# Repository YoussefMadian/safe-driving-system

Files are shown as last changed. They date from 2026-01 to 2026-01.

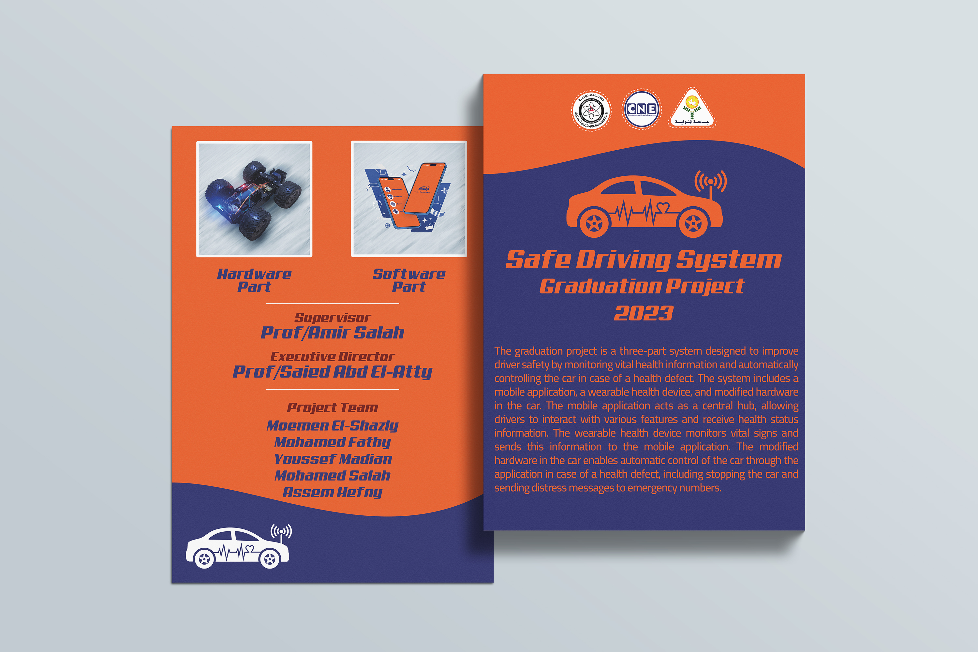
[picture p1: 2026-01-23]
Prints/Flyers/flyer.jpg

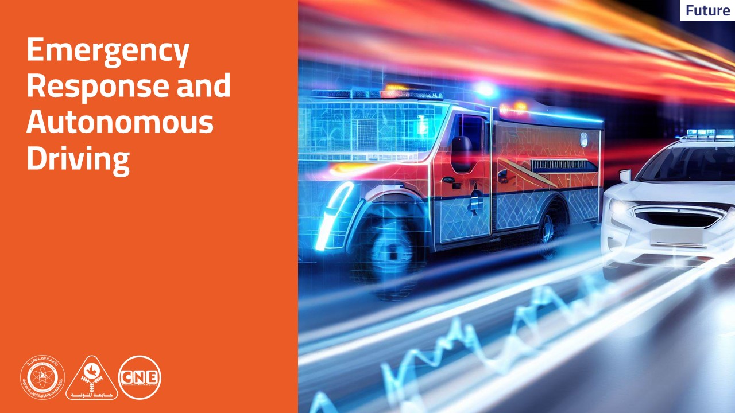
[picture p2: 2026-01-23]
Presentation/Photos/Slide62.JPG

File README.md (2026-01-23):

# safe-driving-system

## Overview
The **Safe Driving System** is an innovative graduation project designed to enhance road safety by monitoring drivers’ health conditions in real time. The system addresses a critical risk factor in driving accidents: sudden health issues that may impair a driver’s ability to operate a vehicle safely.

By combining **wearable health technology**, **wireless connectivity**, and a **mobile application**, the system provides continuous health monitoring, early detection of abnormal conditions, and timely alerts to assist drivers when needed.

---

## Problem Statement
Drivers may experience unexpected health complications such as abnormal heart rate or blood pressure fluctuations while driving. These conditions can significantly increase the risk of accidents if not detected early.

Traditional vehicles lack integrated systems capable of monitoring the driver's health status and responding intelligently to such situations.

---

## System Objectives
- Monitor vital health signs of the driver in real time  
- Detect abnormal physiological changes that may affect driving safety  
- Alert the driver immediately when critical conditions are detected  
- Enhance road safety and reduce accident risks caused by health issues  

---

## System Architecture
The Safe Driving System consists of **two main components**:

### 1. Mobile Application
- Acts as the central control and monitoring hub  
- Displays real-time health data in a user-friendly interface  
- Communicates with the wearable device via **Wi-Fi connection through the vehicle**  
- Sends alerts and notifications when abnormal health conditions are detected  

### 2. Wearable Health Device
- Worn by the driver during driving  
- Equipped with sensors to monitor vital signs such as:
  - Heart rate  
  - Blood pressure  
  - Other relevant physiological parameters  
- Continuously transmits health data to the mobile application  

---

## How the System Works
1. The wearable device continuously monitors the driver’s vital signs  
2. Health data is transmitted wirelessly to the mobile application  
3. The application analyzes incoming data in real time  
4. If abnormal values are detected:
   - The driver is alerted immediately  
   - The system suggests appropriate actions (rest, stop driving, seek medical help, etc.)  

---

## Technologies Used
- Wearable health sensors  
- Wi-Fi communication  
- Mobile application interface  
- Embedded system integration  
- Real-time data monitoring and analysis  

---

## Key Features
- Real-time health monitoring  
- Wireless communication between vehicle, wearable device, and mobile app  
- Early detection of health-related driving risks  
- User-friendly mobile interface  
- Improved driver safety and accident prevention  

---

## Project Scope
This project focuses on enhancing driver safety by integrating health monitoring systems into the driving environment. It demonstrates how **IoT**, **wireless networking**, and **mobile applications** can work together to solve real-world safety challenges.

---

## My Contribution
- System architecture design  
- Network and Wi-Fi integration between system components  
- Mobile application UI design  
- Branding and graphic design (logo, flyer, roll-up, presentation)  
- Documentation and final presentation  

---

## Future Enhancements
- Integration with emergency services  
- GPS-based location sharing during emergencies  
- Cloud-based data storage and analytics  
- AI-based health condition prediction  

---

## License
This project is developed for academic purposes as a graduation project.

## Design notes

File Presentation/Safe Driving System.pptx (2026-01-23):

## Safe Driving System

Graduation Project

2023

## Supervisor

Prof. Amir Salah

## Team Members

Youssef Madian

Asem Hefny

Mohamed Fathy

Mohamed Salah

Moemen El-Shazly

## Why Do We Need “Safe Driving System” ?

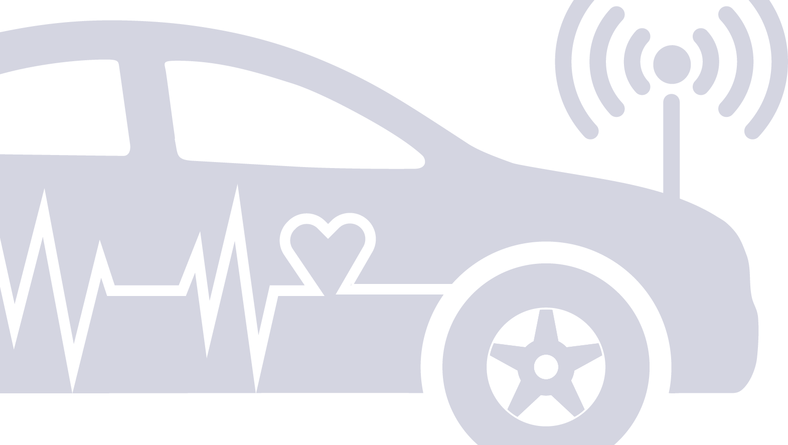
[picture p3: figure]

## Problem Statement

Every day, millions of people get behind the wheel, but what happens when a driver experiences a sudden health issue?

## Statistics On Deaths And Accidents

Globally, an estimated 1.6 million people die each year in road traffic crashes. Of these, up to 10%
(130,000) are believed to be the result of drivers experiencing a health problem while driving.
The leading health problems that commonly cause drivers to be involved in accidents are:
[Sudden cardiac arrest-Stroke-Diabetes-Seizures]

7.88 Billion

1.6 Million

130 Thousands

## The Need For A Solution !

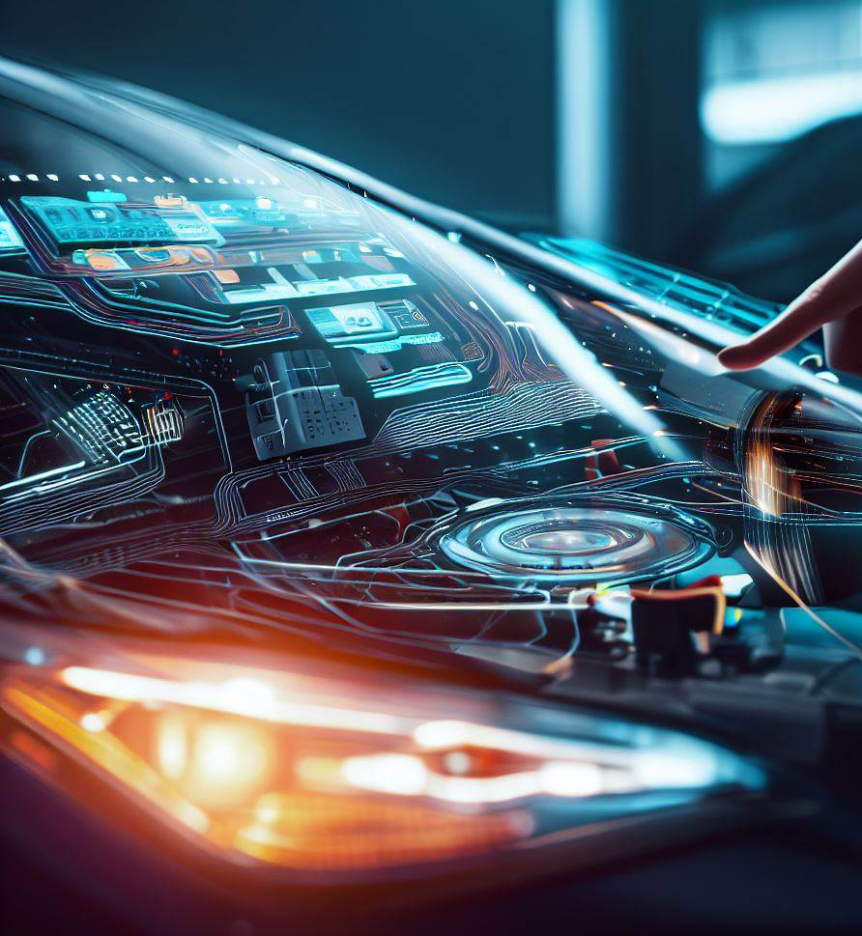
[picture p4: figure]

## Introduction About The Safe Driving System

This is where our solution “Safe Driving System” comes in. It's a three-part system consisting of a mobile
application and a wearable health device beside the hardware part in the simulator car.

## Introduction About The Safe Driving System

The mobile application serves as the central hub, providing a user-friendly interface for drivers to interact with various features and receive vital health status information.

## Introduction About The Safe Driving System

The wearable health device, on the other hand, monitors vital signs such as hearth rate and blood pressure and send this information to the mobile application.

## Introduction About The Safe Driving System

The modified hardware in the simulator car allows us to automatically control the car through the application after a health defect occurs, where the car is stopped and distress messages are sent to the specified emergency numbers.

## Project Overview

Servo Motor180

ESP8266

Arduino

DC Motor

L298d H-Bridge

I2C Logic Converter

Wearable Device

Application

## Outlines

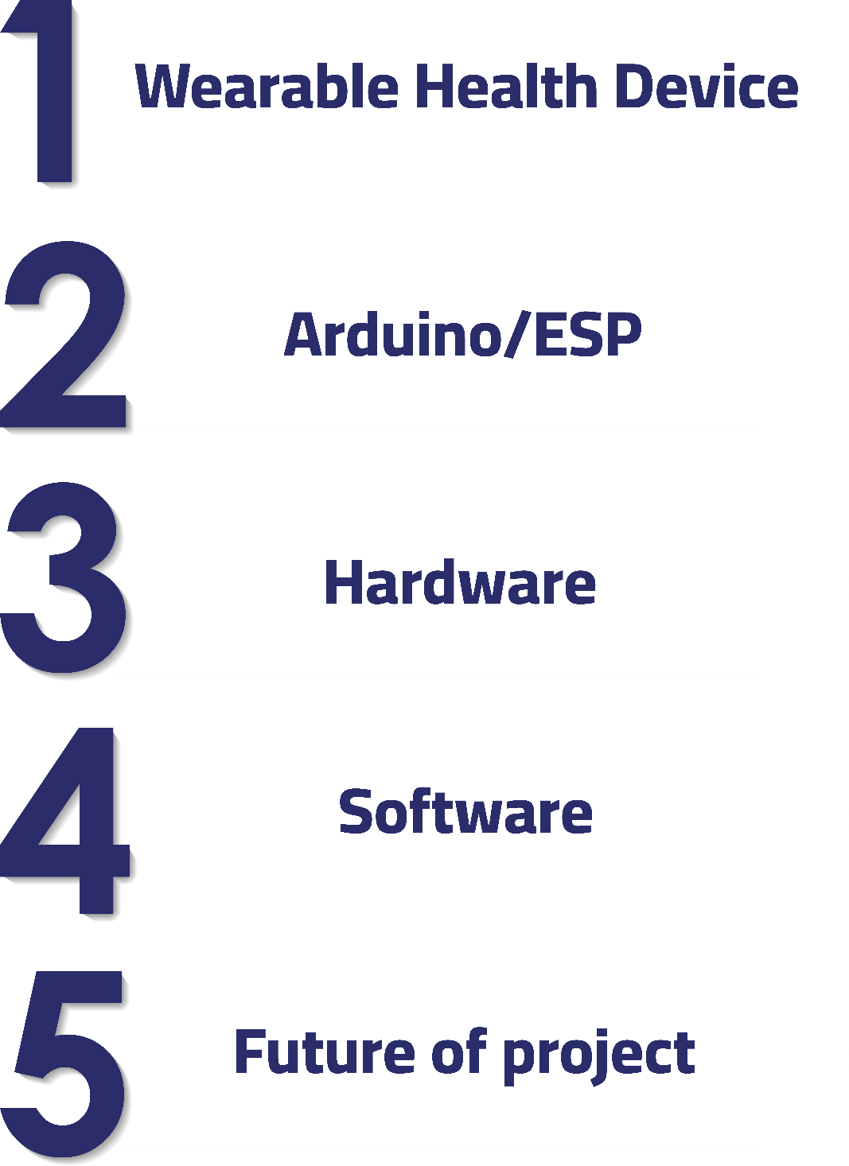
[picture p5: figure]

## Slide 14

Wearable Health Device

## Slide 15

Wearable

Why Did We Use This Part ?

- Remotely, monitoring the vital signs of the driver to early detection of health problems

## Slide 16

Wearable

EX:

RFID Tags

[RFID Tag Tattoo]

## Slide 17

Arduino Uno

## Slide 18

Arduino Uno

Why Did We Use This Part ?

Open hardware source

Micro controller board based on ATmega328p

Technical specifications

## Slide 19

Arduino Uno

Microcontroller | ATmega328
Operating Voltage | 5V
Input Voltage (recommended) | 7-12V
Input Voltage (limits) | 6-20V
Digital I/O Pins | 14 (of which 6 provide PWM output)
Analog Input Pins | 6
DC Current per I/O Pin | 40 mA
DC Current for 3.3V Pin | 50 mA
Flash Memory | 32 KB (ATmega328) of which 0.5 KB used by boot loader
SRAM | 2 KB (ATmega328)
EEPROM | 1 KB (ATmega328)
Clock Speed | 16 MHz

Technical Specifications

## Digital input/output

Arduino Uno

Basic
Parts

ATMEGA16U2
Convert from
UART to USB

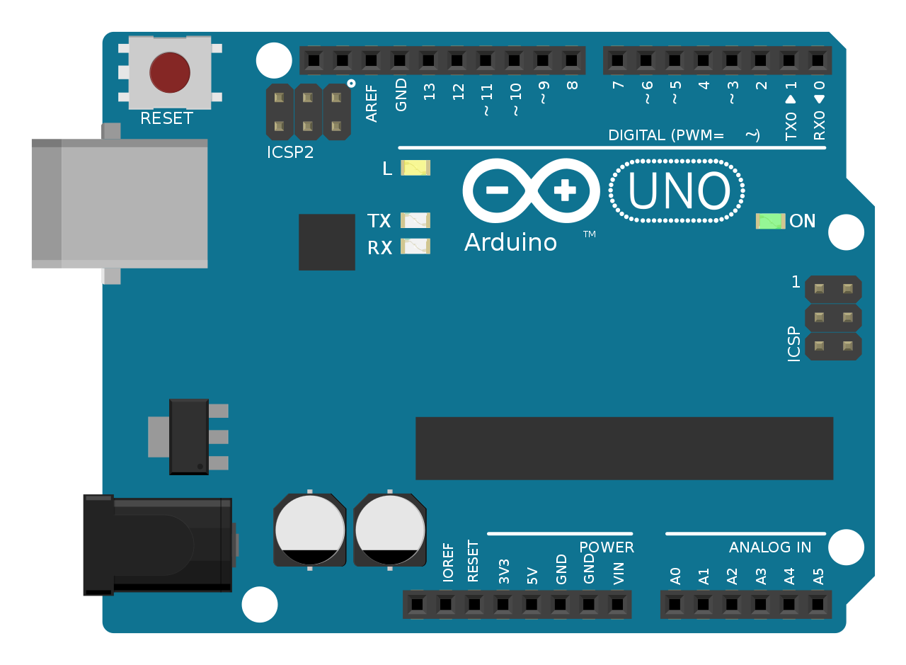
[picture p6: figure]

Reset button

USB

Input
voltage
7-12V

Output
5v&3.3V

Analog Inputs

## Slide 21

ESP 8266

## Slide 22

ESP 8266

Why Did We Use This Part ?

Easy to program: it can be programmed using the Arduino IDE.

Wi-Fi capability: it’s equipped with Wi-Fi microcontroller, which allows it to connect to the internet and communicate with other devices over the network wirelessly.

Real-time monitoring: it can be used to connect sensors and other monitoring devices.

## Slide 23

ESP 8266

NodeMCUBasic Parts

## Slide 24

ESP

I2C
[Inter-Integrated Circuit]

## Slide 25

ESP 8266

What is I2C ?

- It’s a protocol for communication between microcontrollers and other electronic devices.
- The ESP8266 microcontroller [which is used in the ESP8266 and NodeMCU boards] has built-in hardware support for I2C communication.

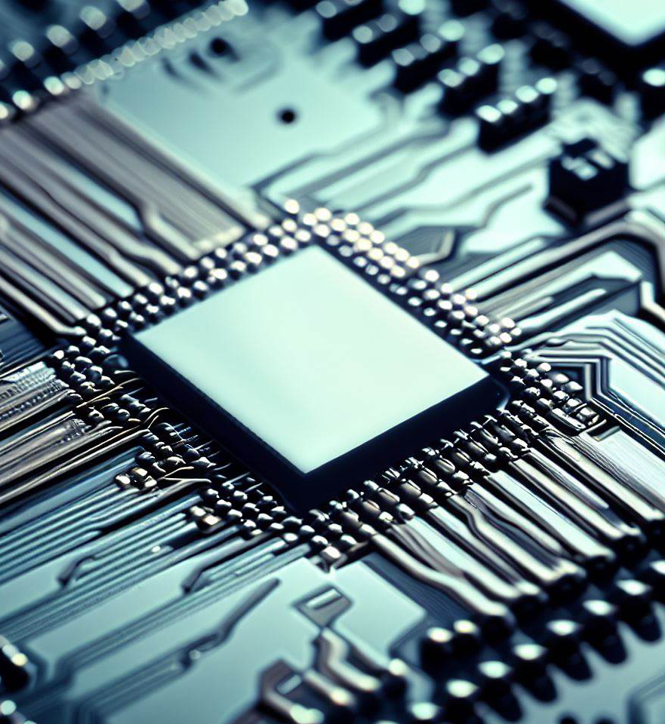
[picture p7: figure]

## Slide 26

ESP 8266

Why Did We Choose I2C Not SPI?

- I2C is a simpler and slower protocol that operates in half-duplex mode.
- I2C is a multi-master protocol, which means multiple devices can be connected to the same bus.
- I2C is suitable for applications with low data rates and low power consumption, such as sensors, and real-time clocks.

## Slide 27

How I2C Work ?

ESP 8266

Wired Used | 2 Wires
Max Speed | Standard Mode>100 kbps Fast Mode>400 kbps High Speed Mode>3.4 Mbps Ultra Fast Mode>5 Mbps
Synchronous or Asynchronous? | Synchronous
Serial or Parallel ? | Serial
Max # of Masters | Unlimited
Max # of Slaves | 1008

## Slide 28

ESP 8266

How I2C Work ?

SDA (Serial Data) : The line for the master and slave to send and receive data.
SCL (Serial Clock) : The line that carries the clock signal.

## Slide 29

ESP 8266

I2C Frames

- Start Condition
- Stop Condition
- Address Frame
- Read/Write Bit
- ACK/NACK Bit

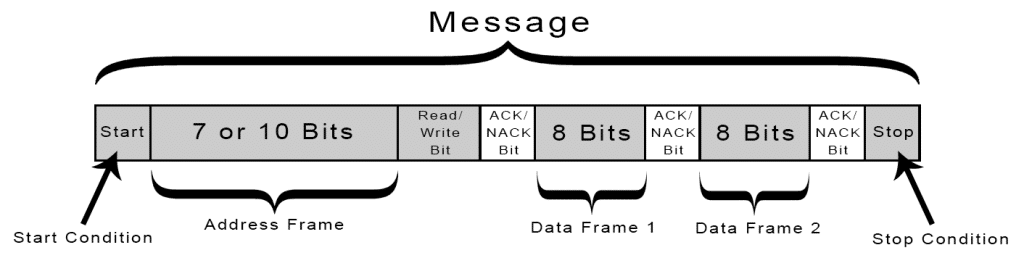
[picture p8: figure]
Introduction to I2C - Message, Frame, and Bit

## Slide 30

ESP 8266

STEPS OF I2C DATA TRANSMISSION

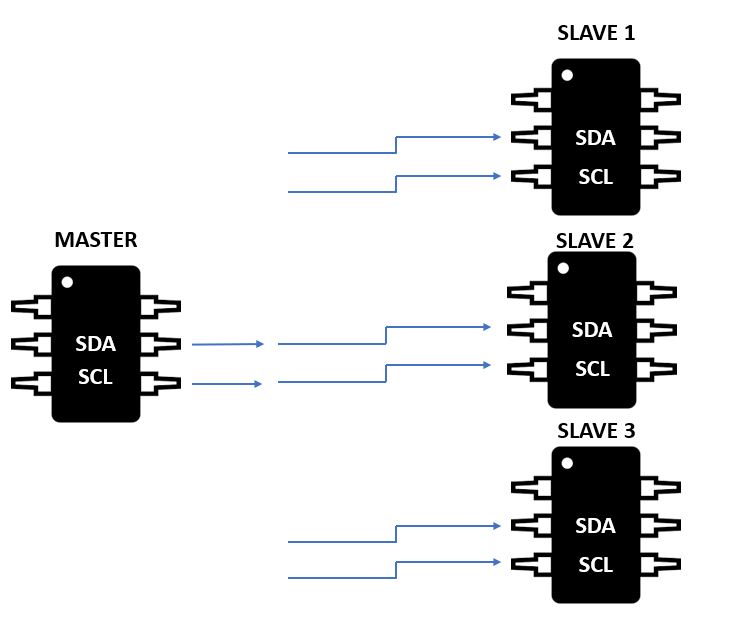
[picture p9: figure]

[1]

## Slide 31

ESP 8266

STEPS OF I2C DATA TRANSMISSION

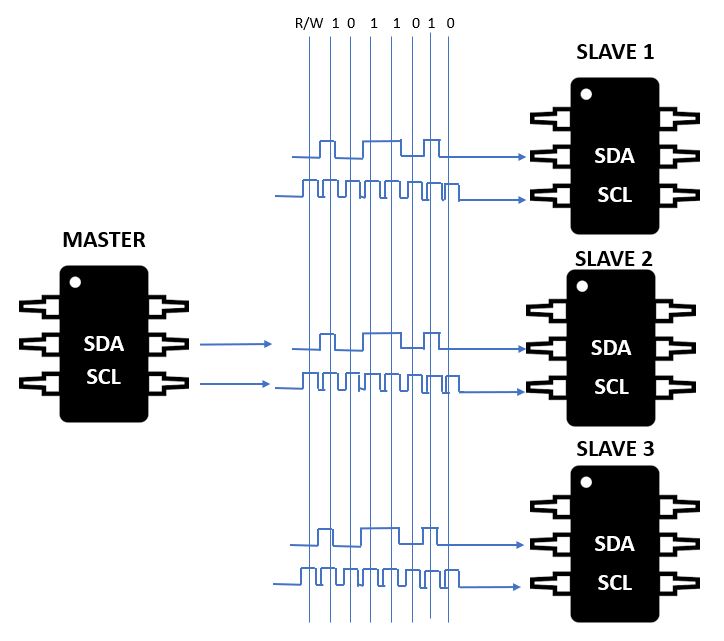
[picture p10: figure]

Address
0110000

[2]

Address
1001000

Address
0101101

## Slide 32

ESP 8266

STEPS OF I2C DATA TRANSMISSION

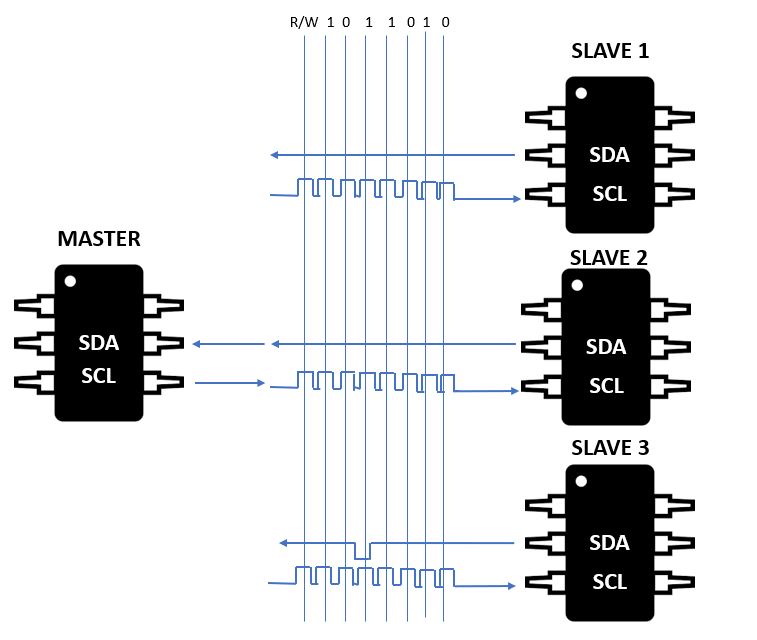
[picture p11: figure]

Address
0110000

[3]

Address
1001000

Address
0101101

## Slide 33

ESP 8266

STEPS OF I2C DATA TRANSMISSION

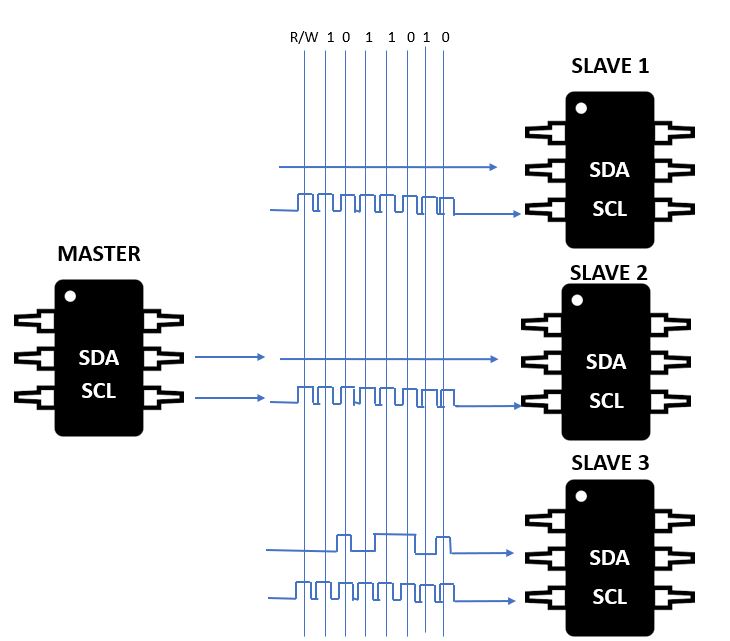
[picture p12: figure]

[4]

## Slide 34

ESP 8266

STEPS OF I2C DATA TRANSMISSION

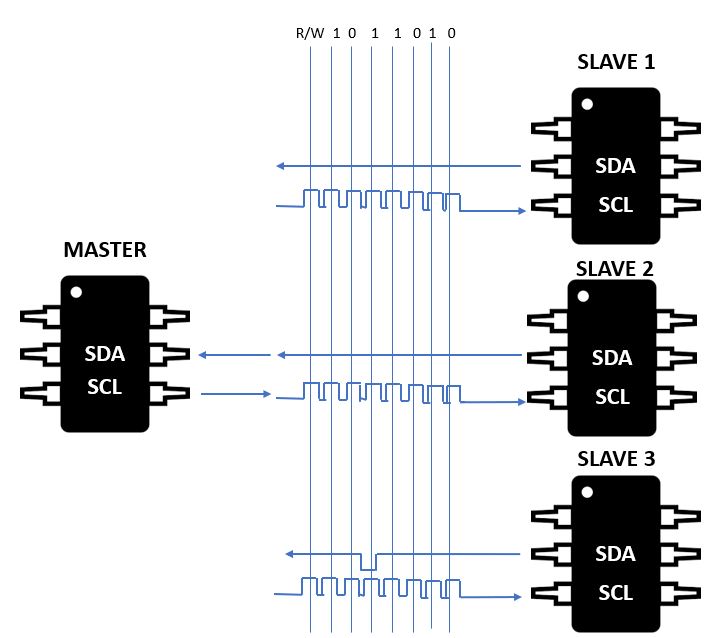
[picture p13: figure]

[5]

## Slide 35

ESP 8266

STEPS OF I2C DATA TRANSMISSION

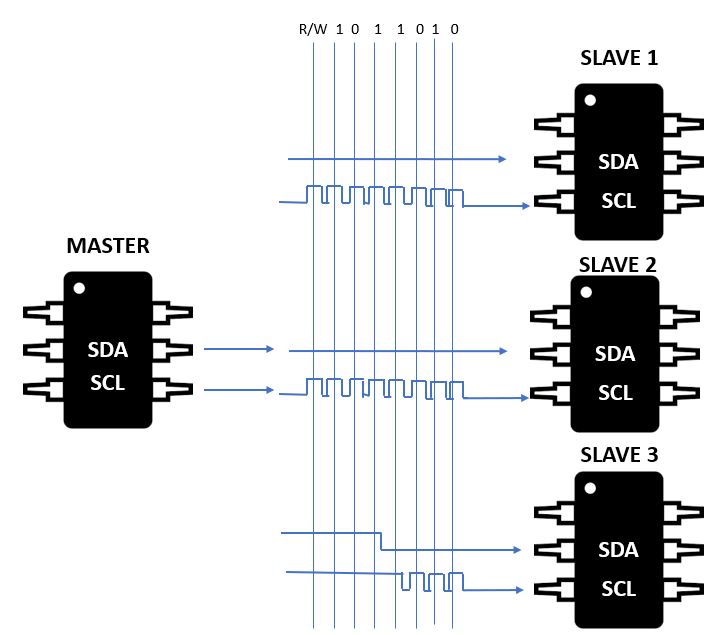
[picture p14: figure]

[6]

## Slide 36

Hardware

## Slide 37

Hardware

Basic Components

- Arduino Uno
- ESP2866-12E
- L298d H-Bridge
- DC-DC Converter Booster
- Servo Motor 180°
- DC Motor 5V
- Li ion Charger Module
- I2C Logic Converter
- Battery Li ion 3.7V-2200mAh

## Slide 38

Hardware

NodeMCU

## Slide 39

Hardware

DC H-Bridge

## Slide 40

DC-DC Converter Booster

Hardware

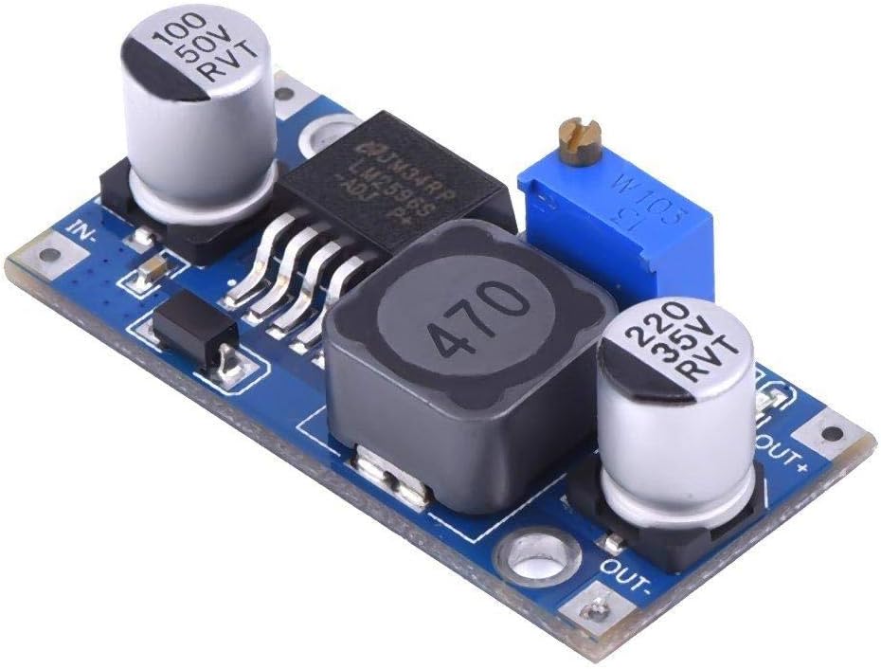
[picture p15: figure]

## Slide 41

I2C Logic Converter

Hardware

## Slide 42

Hardware

Li ion Charger

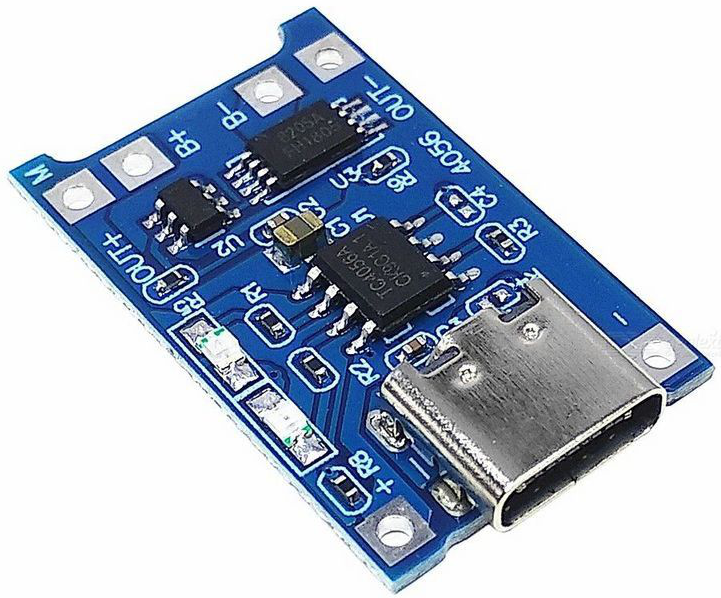
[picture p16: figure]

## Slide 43

Hardware

Battery Li ion 3.7V

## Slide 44

Hardware

Servo Motor

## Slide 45

Car Circuit PCB

Top Part

Hardware

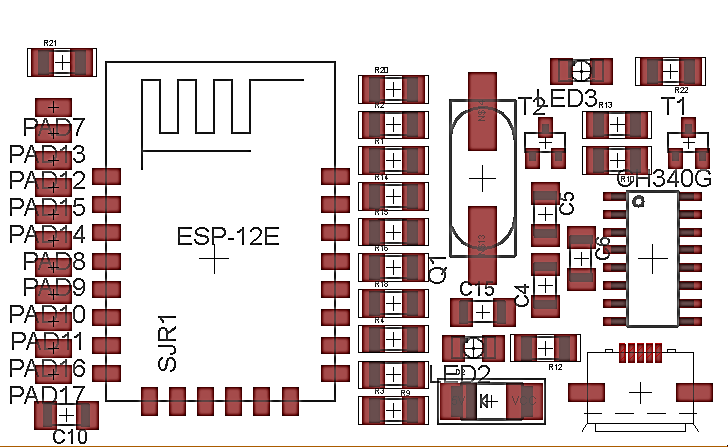
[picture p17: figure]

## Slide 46

Car Circuit PCB

Bottom Part

Hardware

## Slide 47

Software

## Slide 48

Software

Software Parts

- Mobile Application
- Arduino Uno
- ESP2866

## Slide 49

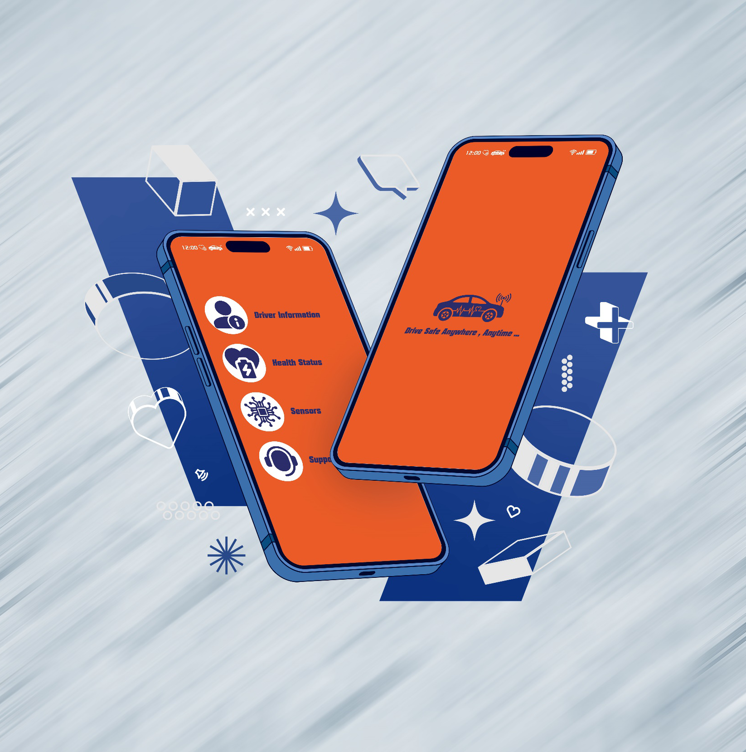
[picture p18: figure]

Software

Mobile Application

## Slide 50

Software

Mobile Application

UI Design

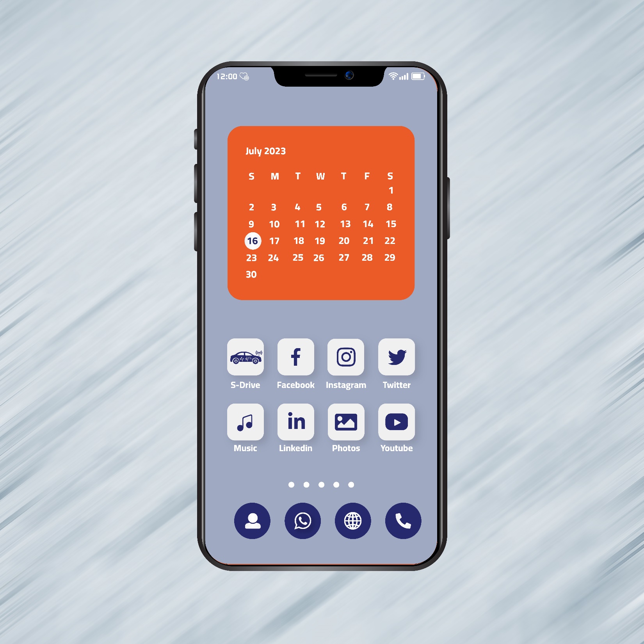
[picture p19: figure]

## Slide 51

Software

Mobile Application

UI Design

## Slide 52

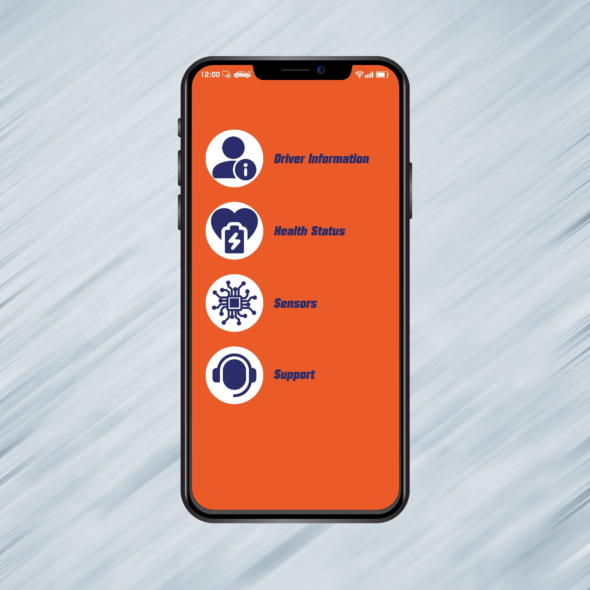
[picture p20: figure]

Software

Mobile Application

UI Design

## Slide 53

Software

Mobile Application

UI Design

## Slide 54

Software

Mobile Application

UI Design

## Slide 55

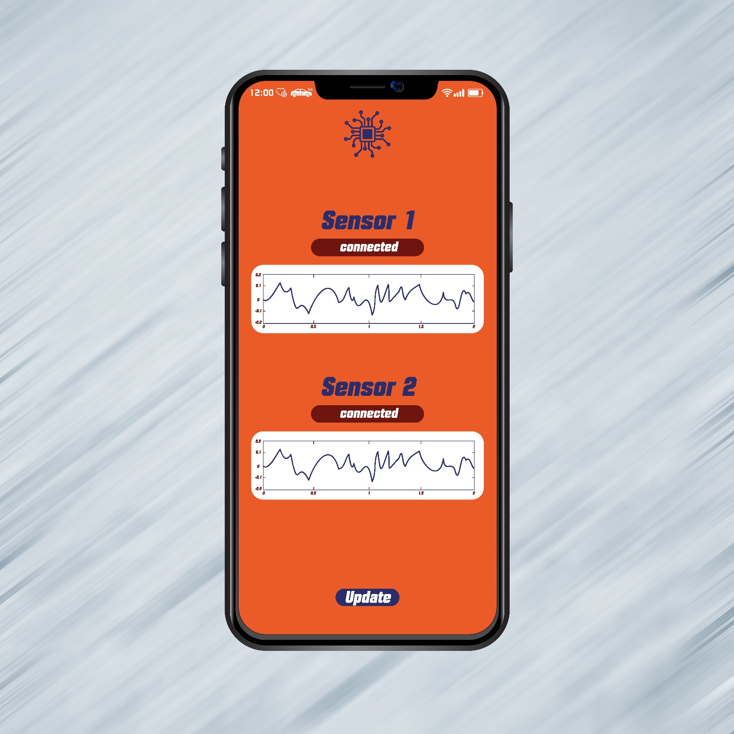
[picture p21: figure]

Software

Mobile Application

UI Design

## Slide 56

Software

Mobile Application

UI Design

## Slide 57

Software

A preliminary application was designed by “MIT App Inventor” website until the project is developed further in the future, as we will know in the “future of the project” part.

Application Building

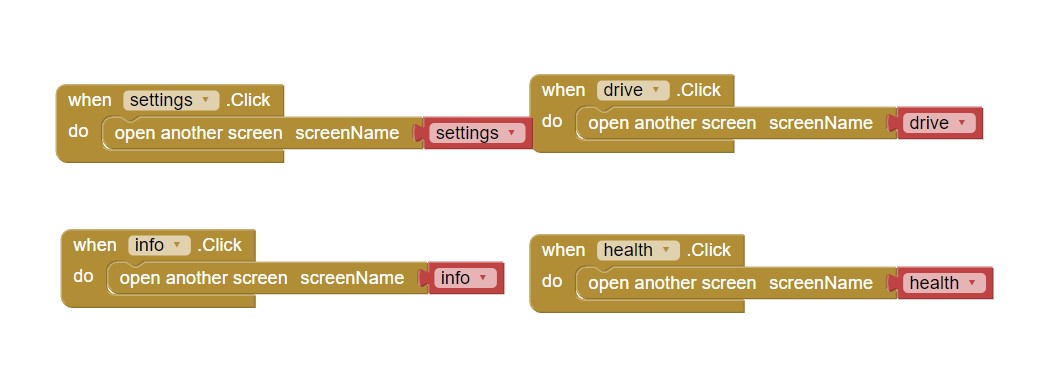
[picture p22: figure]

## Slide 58

Arduino Coding

Software

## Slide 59

ESP-8266 Coding

Software

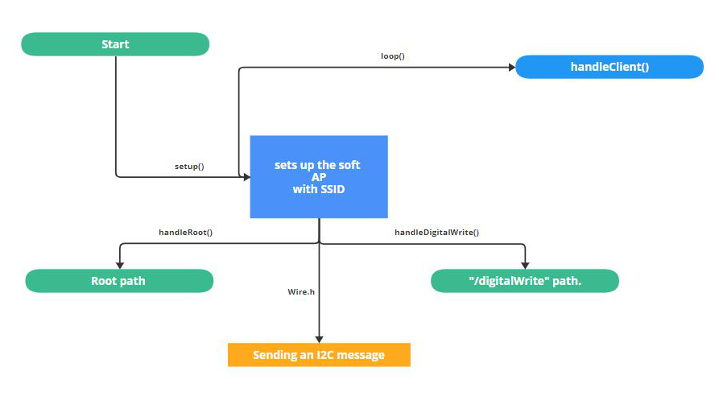
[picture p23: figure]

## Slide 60

Future Of Project

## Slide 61

Future

Future Plans

- Artificial Intelligence
- Emergency Response and Autonomous Driving
- Driver Profiling
- Driver Feedback
- Cloud-Based Storage
- Internet of Things (IoT)
- Sensor Fusion Technology

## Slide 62

Future

Artificial Intelligence

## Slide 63

Future

Emergency Response and Autonomous Driving

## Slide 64

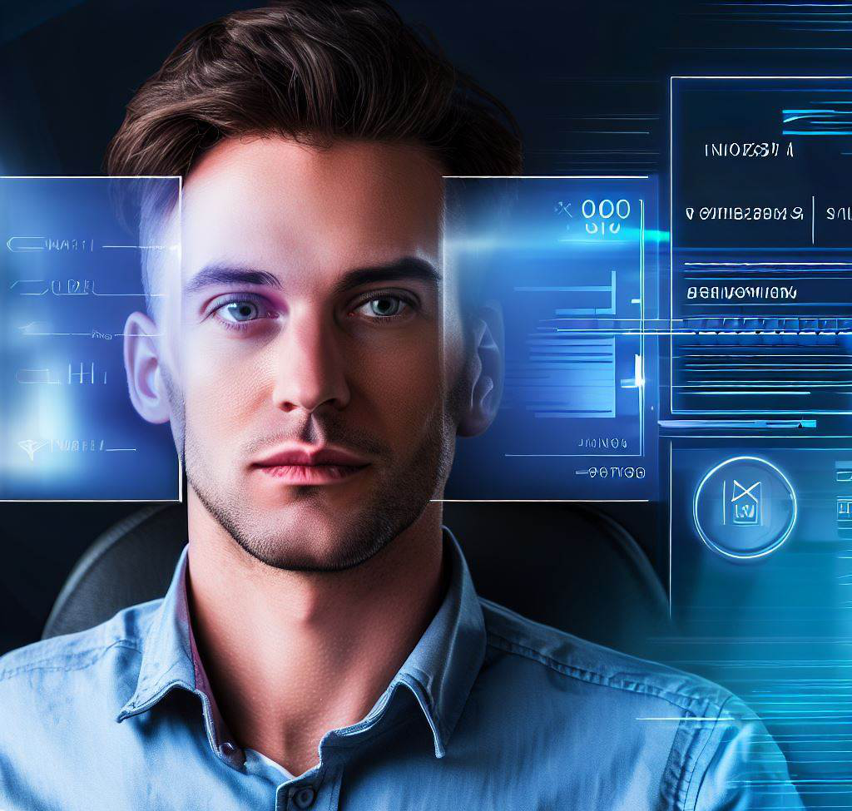
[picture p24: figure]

Future

Driver Profiling

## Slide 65

Future

Driver Feedback

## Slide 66

Future

Cloud-Based Storage

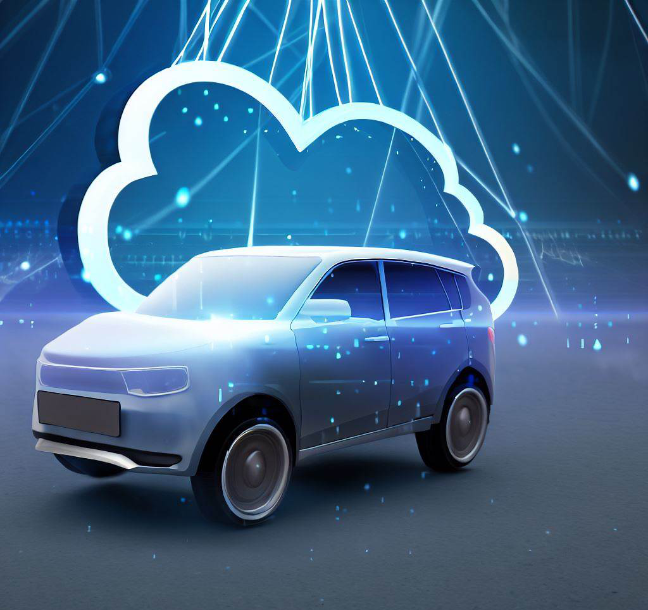
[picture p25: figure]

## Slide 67

Future

Internet of Things (IoT)

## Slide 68

Sensor
Fusion
Technology

- Wearable Sensors
- Sensor Fusion Algorithm
- Car's Sensors
- Data Processing and Analysis
- Artificial Intelligence Algorithms
- Real-time Insights

Future

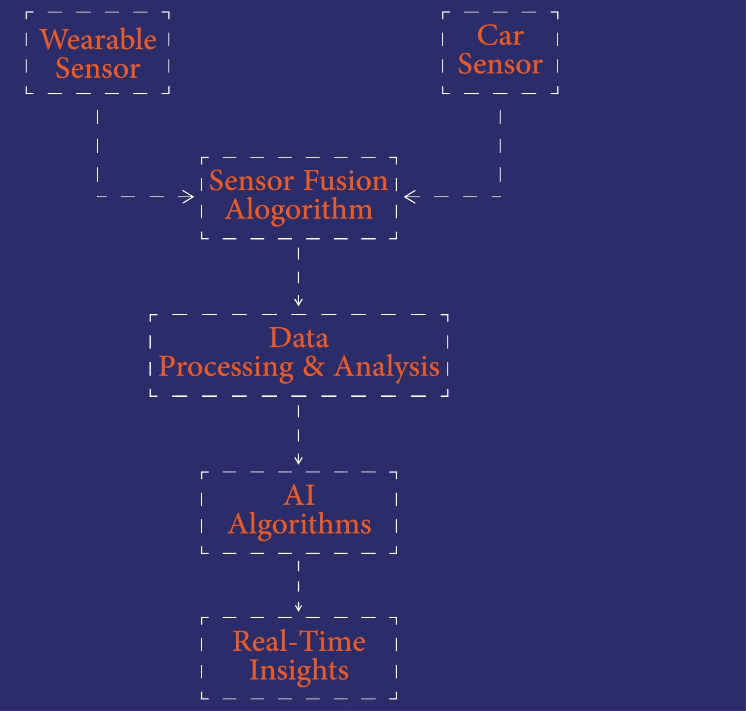
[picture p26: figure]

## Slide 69

Sensor Fusion Technology

Future

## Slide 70

Thanks…..

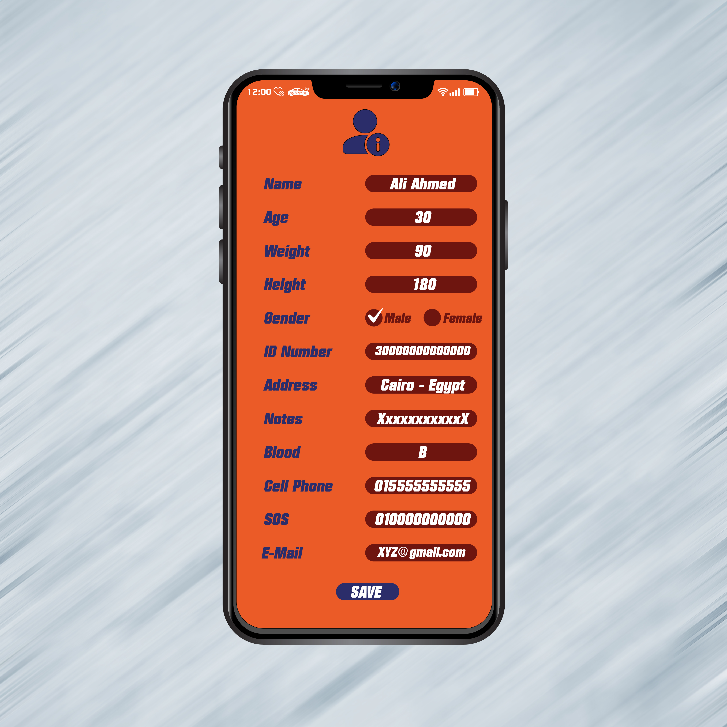
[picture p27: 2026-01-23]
Application UI Design/Artboard 3.jpg

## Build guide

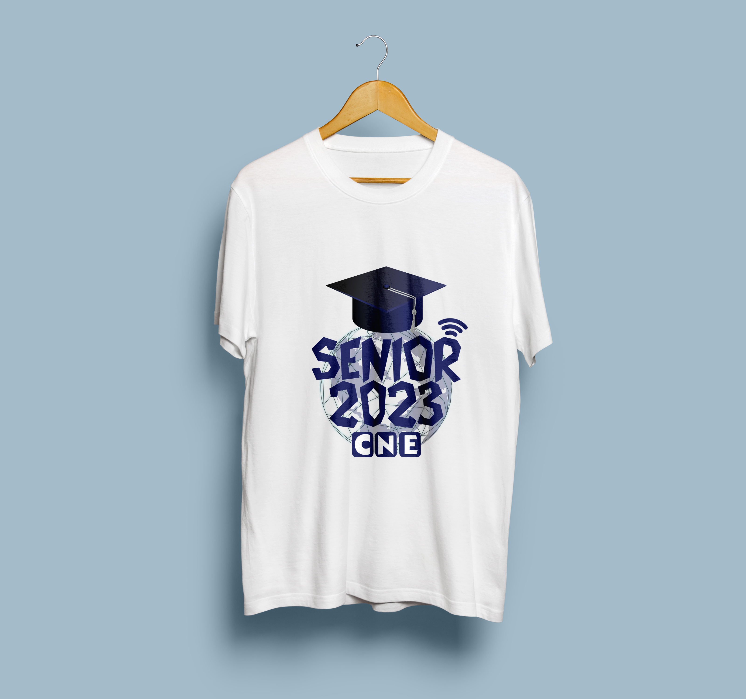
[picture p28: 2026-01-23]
Prints/T-Shirt/T-Shirt.jpg

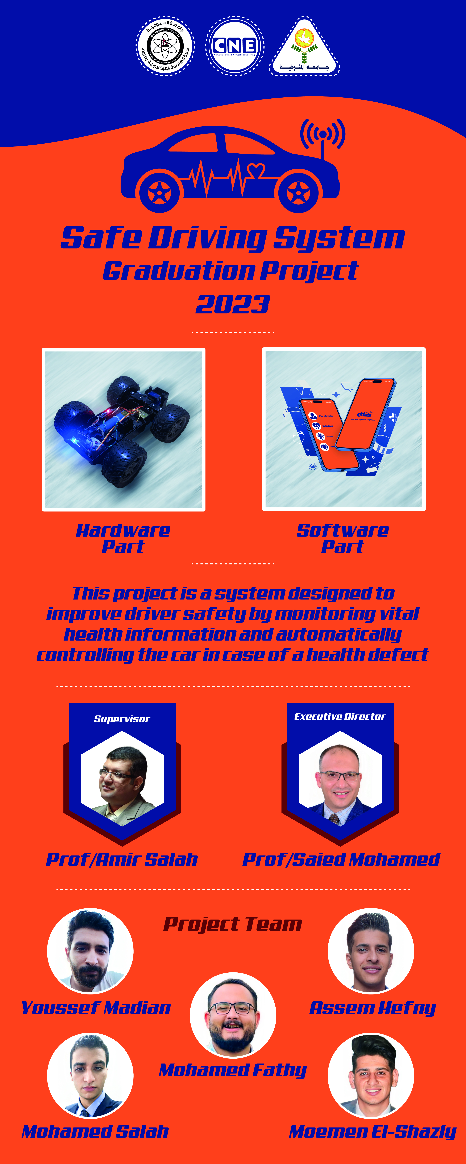
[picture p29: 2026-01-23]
Prints/Roll-up/Roll-Up.jpg

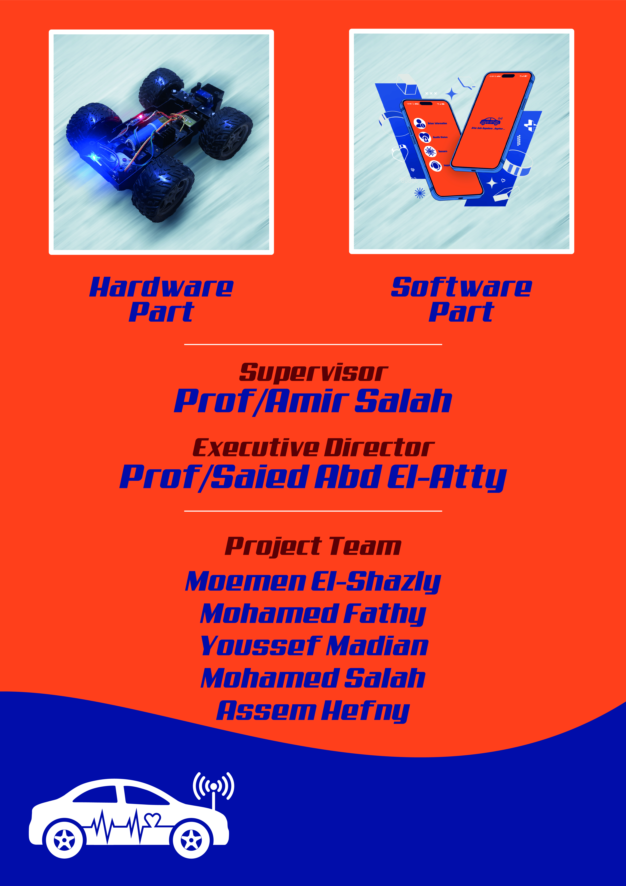
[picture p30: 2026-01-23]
Prints/Flyers/back.jpg

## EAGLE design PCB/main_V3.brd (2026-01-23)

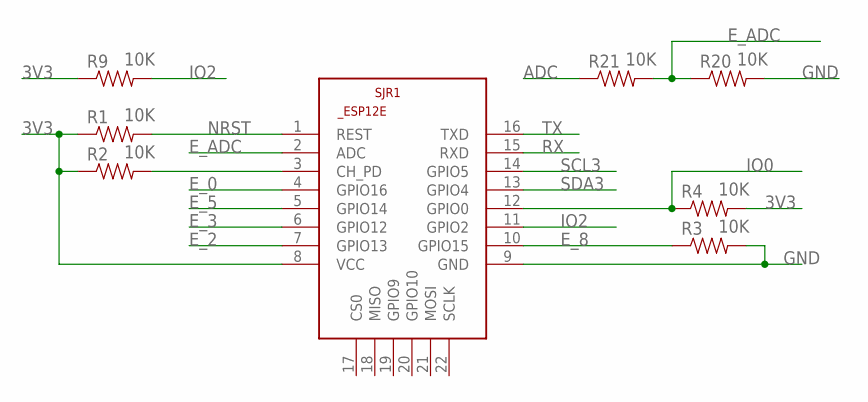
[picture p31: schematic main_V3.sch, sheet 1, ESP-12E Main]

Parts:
R1, R2, R3, R4, R9, R20, R21: 10K; 1206
SJR1: ESP8266-12EESP12E; ESP8266-ESP12E

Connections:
3V3: R1.1, R2.1, R4.2, R9.1, SJR1.8 (VCC); also elsewhere on the board
ADC: R21.1; also elsewhere on the board
E_0: SJR1.4 (GPIO16); also elsewhere on the board
E_2: SJR1.7 (GPIO13); also elsewhere on the board
E_3: SJR1.6 (GPIO12); also elsewhere on the board
E_5: SJR1.5 (GPIO14); also elsewhere on the board
E_8: R3.1, SJR1.10 (GPIO15); also elsewhere on the board
E_ADC: R20.1, R21.2, SJR1.2 (ADC)
GND: R3.2, R20.2, SJR1.9 (GND); also elsewhere on the board
IO0: R4.1, SJR1.12 (GPIO0); also elsewhere on the board
IO2: R9.2, SJR1.11 (GPIO2)
unnamed: R2.2, SJR1.3 (CH_PD)
NRST: R1.2, SJR1.1 (REST); also elsewhere on the board
RX: SJR1.15 (RXD); also elsewhere on the board
SCL3: SJR1.14 (GPIO5); also elsewhere on the board
SDA3: SJR1.13 (GPIO4); also elsewhere on the board
TX: SJR1.16 (TXD); also elsewhere on the board

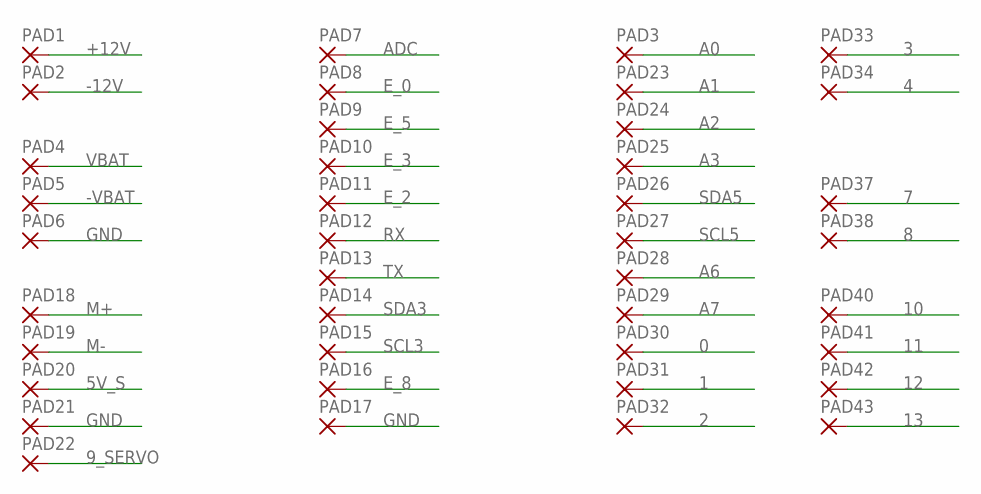
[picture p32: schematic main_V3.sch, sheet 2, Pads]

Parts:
PAD1, PAD2, PAD4, PAD5, PAD6: WIREPADSMD5-2,5; 5-2,5
PAD3, PAD7, PAD8, PAD9, PAD10, PAD11, PAD12, PAD13, PAD14, PAD15, PAD16, PAD17, PAD18, PAD19, PAD20, PAD21, PAD22, PAD23, PAD24, PAD25, PAD26, PAD27, PAD28, PAD29, PAD30, PAD31, PAD32, PAD33, PAD34, PAD37, PAD38, PAD40, PAD41, PAD42, PAD43: WIREPADSMD1,27-254; SMD1,27-2,54

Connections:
0: PAD30.1; also elsewhere on the board
1: PAD31.1; also elsewhere on the board
2: PAD32.1; also elsewhere on the board
3: PAD33.1; also elsewhere on the board
4: PAD34.1; also elsewhere on the board
5V_S: PAD20.1; also elsewhere on the board
7: PAD37.1; also elsewhere on the board
8: PAD38.1; also elsewhere on the board
9_SERVO: PAD22.1; also elsewhere on the board
10: PAD40.1; also elsewhere on the board
11: PAD41.1; also elsewhere on the board
12: PAD42.1; also elsewhere on the board
13: PAD43.1; also elsewhere on the board
+12V: PAD1.1; also elsewhere on the board
-12V: PAD2.1; also elsewhere on the board
-VBAT: PAD5.1; also elsewhere on the board
A0: PAD3.1; also elsewhere on the board
A1: PAD23.1; also elsewhere on the board
A2: PAD24.1; also elsewhere on the board
A3: PAD25.1; also elsewhere on the board
A6: PAD28.1; also elsewhere on the board
A7: PAD29.1; also elsewhere on the board
ADC: PAD7.1; also elsewhere on the board
E_0: PAD8.1; also elsewhere on the board
E_2: PAD11.1; also elsewhere on the board
E_3: PAD10.1; also elsewhere on the board
E_5: PAD9.1; also elsewhere on the board
E_8: PAD16.1; also elsewhere on the board
GND: PAD6.1, PAD17.1, PAD21.1; also elsewhere on the board
M+: PAD18.1; also elsewhere on the board
M-: PAD19.1; also elsewhere on the board
RX: PAD12.1; also elsewhere on the board
SCL3: PAD15.1; also elsewhere on the board
SCL5: PAD27.1; also elsewhere on the board
SDA3: PAD14.1; also elsewhere on the board
SDA5: PAD26.1; also elsewhere on the board
TX: PAD13.1; also elsewhere on the board
VBAT: PAD4.1; also elsewhere on the board

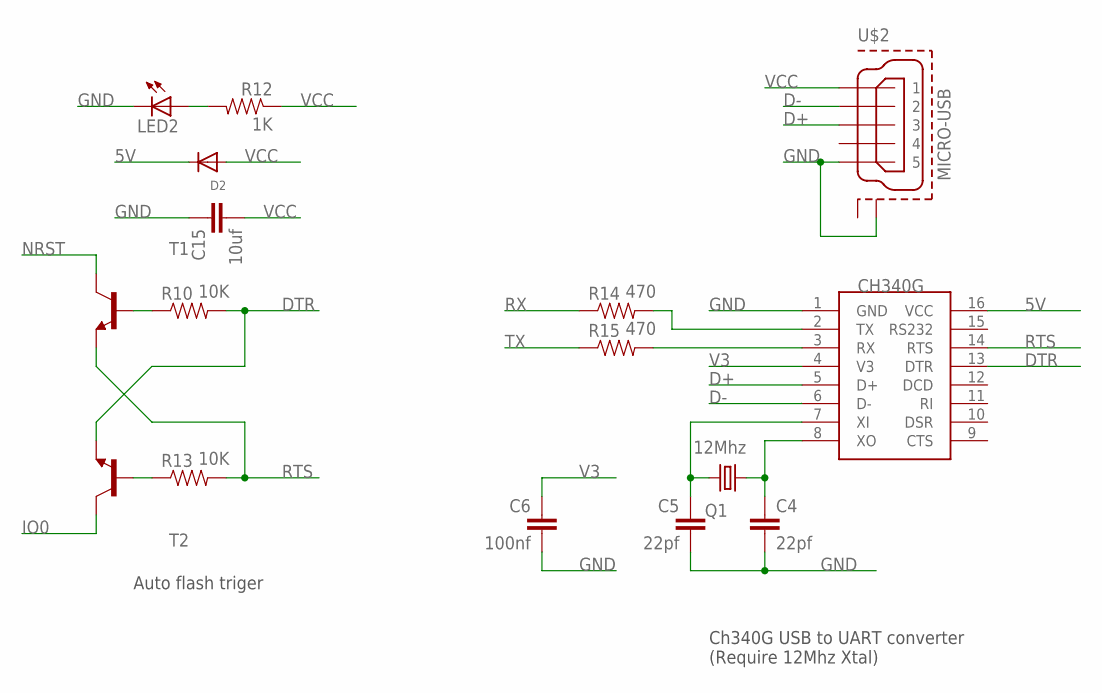
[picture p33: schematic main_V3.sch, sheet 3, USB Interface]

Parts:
C4, C5: 22pf; C1206K
C6: 100nf; C1206K
C15: 10uf; C1206K
D2: DIODESMA; SMADIODE
LED2: LEDSMT1206; 1206
Q1: 12Mhz; CSM-7X-DU
R10, R13: 10K; 1206
R12: 1K; 1206
R14, R15: 470; 1206
T1, T2: MMBT5551LT1-NPN-SOT23-BEC; SOT23-BEC
U$1: CH340G; SOIC16
U$2: MICRO-USB; 47589-0001

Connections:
5V: D2.C, U$1.16 (VCC); also elsewhere on the board
D+: U$1.5 (D+), U$2.3
D-: U$1.6 (D-), U$2.2
DTR: R10.2, T2.E, U$1.13 (DTR)
GND: C4.2, C5.2, C6.2, C15.1, LED2.C, U$1.1 (GND), U$2.5, U$2.P$2 (GND2); also elsewhere on the board
IO0: T2.C; also elsewhere on the board
unnamed: C4.1, Q1.1, U$1.8 (XO)
unnamed: C5.1, Q1.2, U$1.7 (XI)
unnamed: R10.1, T1.B
unnamed: R13.1, T2.B
unnamed: R15.2, U$1.3 (RX)
unnamed: R14.2, U$1.2 (TX)
unnamed: LED2.A, R12.2
NRST: T1.C; also elsewhere on the board
RTS: R13.2, T1.E, U$1.14 (RTS)
RX: R14.1; also elsewhere on the board
TX: R15.1; also elsewhere on the board
V3: C6.1, U$1.4 (V3)
VCC: C15.2, D2.A, R12.1, U$2.1

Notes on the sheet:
Auto flash triger
Ch340G USB to UART converter (Require 12Mhz Xtal)

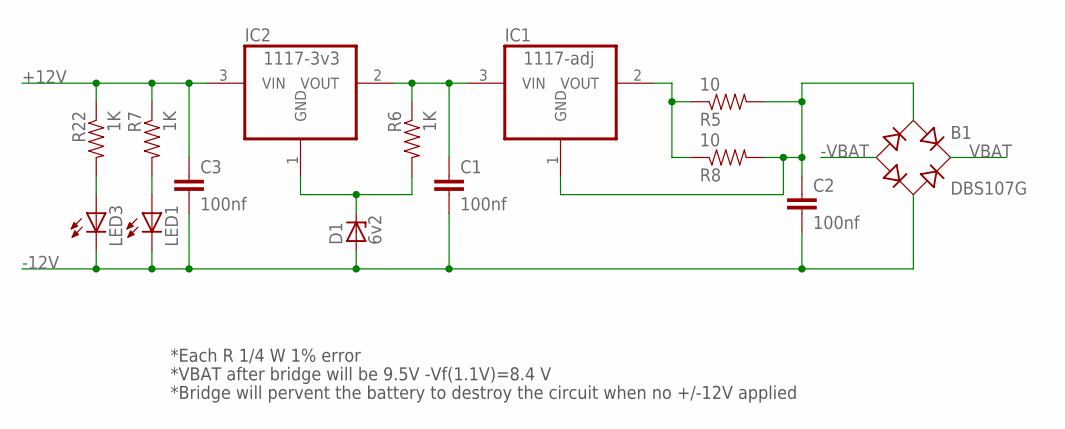
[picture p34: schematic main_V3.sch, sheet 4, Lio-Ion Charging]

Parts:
B1: DBS107G; DBS
C1, C2, C3: 100nf; C1206K
D1: 6v2; SOT23
IC1: 1117-adj; SOT223
IC2: 1117-3v3; SOT223
LED1, LED3: LEDSMT1206; 1206
R5, R8: 10; 1206
R6, R7, R22: 1K; 1206

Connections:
+12V: C3.1, IC2.3 (VIN), R7.1, R22.1; also elsewhere on the board
-12V: B1.AC2, C1.2, C2.2, C3.2, D1.1 (A), LED1.C, LED3.C; also elsewhere on the board
-VBAT: B1.-; also elsewhere on the board
unnamed: D1.3 (C), IC2.1 (GND), R6.2
unnamed: B1.AC1, C2.1, IC1.1 (GND), R5.2, R8.2
unnamed: IC1.2 (VOUT), R5.1, R8.1
unnamed: C1.1, IC1.3 (VIN), IC2.2 (VOUT), R6.1
unnamed: LED1.A, R7.2
unnamed: LED3.A, R22.2
VBAT: B1.+; also elsewhere on the board

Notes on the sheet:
*Each R 1/4 W 1% error
*VBAT after bridge will be 9.5V -Vf(1.1V)=8.4 V
*Bridge will pervent the battery to destroy the circuit when no +/-12V applied

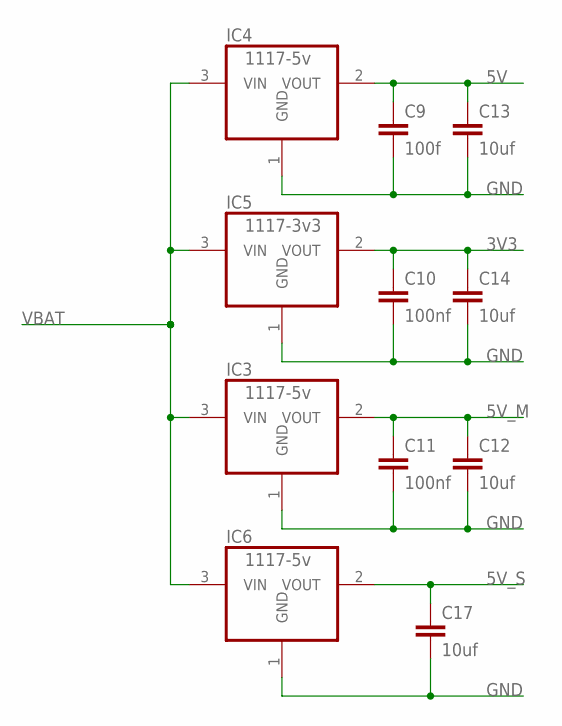
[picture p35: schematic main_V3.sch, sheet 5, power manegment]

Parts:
C9: 100f; C1206K
C10, C11: 100nf; C1206K
C12, C13, C14, C17: 10uf; C1206K
IC3, IC4, IC6: 1117-5v; SOT223
IC5: 1117-3v3; SOT223

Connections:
3V3: C10.1, C14.1, IC5.2 (VOUT); also elsewhere on the board
5V: C9.1, C13.1, IC4.2 (VOUT); also elsewhere on the board
5V_M: C11.1, C12.1, IC3.2 (VOUT); also elsewhere on the board
5V_S: C17.1, IC6.2 (VOUT); also elsewhere on the board
GND: C9.2, C10.2, C11.2, C12.2, C13.2, C14.2, C17.2, IC3.1 (GND), IC4.1 (GND), IC5.1 (GND), IC6.1 (GND); also elsewhere on the board
VBAT: IC3.3 (VIN), IC4.3 (VIN), IC5.3 (VIN), IC6.3 (VIN); also elsewhere on the board

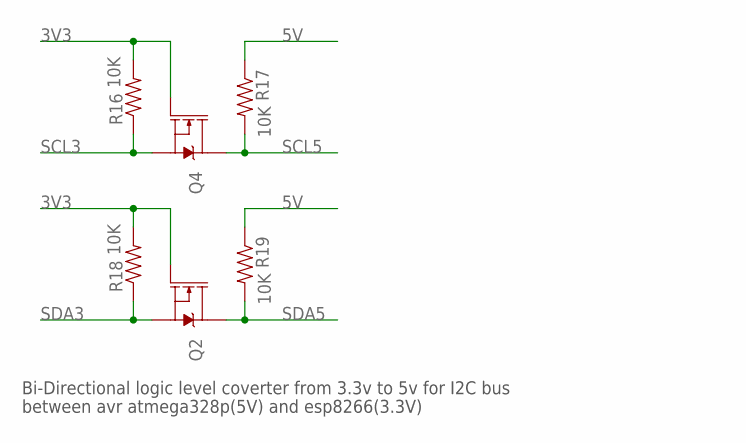
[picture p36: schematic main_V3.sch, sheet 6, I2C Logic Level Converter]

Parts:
Q2, Q4: MOSFET-NCH-BSS138; SOT23-3
R16, R17, R18, R19: 10K; 1206

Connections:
3V3: Q2.1 (G), Q4.1 (G), R16.2, R18.2; also elsewhere on the board
5V: R17.1, R19.1; also elsewhere on the board
SCL3: Q4.2 (S), R16.1; also elsewhere on the board
SCL5: Q4.3 (D), R17.2; also elsewhere on the board
SDA3: Q2.2 (S), R18.1; also elsewhere on the board
SDA5: Q2.3 (D), R19.2; also elsewhere on the board

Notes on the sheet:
Bi-Directional logic level coverter from 3.3v to 5v for I2C bus
between avr atmega328p(5V) and esp8266(3.3V)

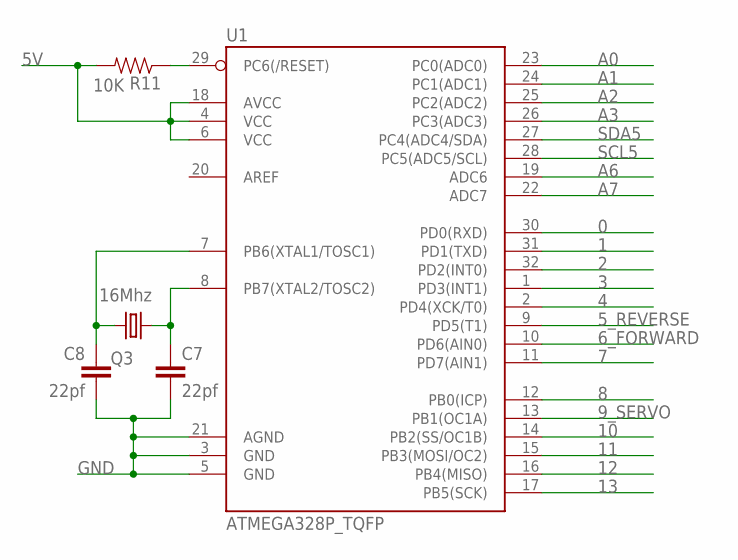
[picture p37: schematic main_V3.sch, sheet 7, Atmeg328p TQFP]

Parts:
C7, C8: 22pf; C1206K
Q3: 16Mhz; CSM-7X-DU
R11: 10K; 1206
U1: ATMEGA328P_TQFP; TQFP32-08

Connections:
0: U1.30 (PD0(RXD)); also elsewhere on the board
1: U1.31 (PD1(TXD)); also elsewhere on the board
2: U1.32 (PD2(INT0)); also elsewhere on the board
3: U1.1 (PD3(INT1)); also elsewhere on the board
4: U1.2 (PD4(XCK/T0)); also elsewhere on the board
5V: R11.2, U1.4 (VCC), U1.6 (VCC), U1.18 (AVCC); also elsewhere on the board
5_REVERSE: U1.9 (PD5(T1)); also elsewhere on the board
6_FORWARD: U1.10 (PD6(AIN0)); also elsewhere on the board
7: U1.11 (PD7(AIN1)); also elsewhere on the board
8: U1.12 (PB0(ICP)); also elsewhere on the board
9_SERVO: U1.13 (PB1(OC1A)); also elsewhere on the board
10: U1.14 (PB2(SS/OC1B)); also elsewhere on the board
11: U1.15 (PB3(MOSI/OC2)); also elsewhere on the board
12: U1.16 (PB4(MISO)); also elsewhere on the board
13: U1.17 (PB5(SCK)); also elsewhere on the board
A0: U1.23 (PC0(ADC0)); also elsewhere on the board
A1: U1.24 (PC1(ADC1)); also elsewhere on the board
A2: U1.25 (PC2(ADC2)); also elsewhere on the board
A3: U1.26 (PC3(ADC3)); also elsewhere on the board
A6: U1.19 (ADC6); also elsewhere on the board
A7: U1.22 (ADC7); also elsewhere on the board
GND: C7.2, C8.2, U1.3 (GND), U1.5 (GND), U1.21 (AGND); also elsewhere on the board
unnamed: C7.1, Q3.1, U1.8 (PB7(XTAL2/TOSC2))
unnamed: C8.1, Q3.2, U1.7 (PB6(XTAL1/TOSC1))
unnamed: R11.1, U1.29 (PC6(/RESET))
SCL5: U1.28 (PC5(ADC5/SCL)); also elsewhere on the board
SDA5: U1.27 (PC4(ADC4/SDA)); also elsewhere on the board

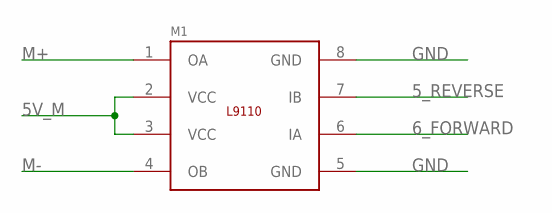
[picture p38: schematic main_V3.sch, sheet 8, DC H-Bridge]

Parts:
M1: L9110; SO8P

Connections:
5V_M: M1.2 (VCC), M1.3 (VCC); also elsewhere on the board
5_REVERSE: M1.7 (IB); also elsewhere on the board
6_FORWARD: M1.6 (IA); also elsewhere on the board
GND: M1.5 (GND), M1.8 (GND); also elsewhere on the board
M+: M1.1 (OA); also elsewhere on the board
M-: M1.4 (OB); also elsewhere on the board

Board: 4 copper layers, 101 parts (61 on the bottom side), 70 nets, no tracks yet.

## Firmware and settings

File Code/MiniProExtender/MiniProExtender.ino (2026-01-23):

/****************************************************************************************************************************\
   
   ***MODEFIED BY Safe Driving System Team
   
   Arduino project "ESP Easy" � Copyright www.esp8266.nu

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
   IDE download    : https://www.arduino.cc/en/Main/Software
   ESP8266 Package : https://github.com/esp8266/Arduino

   Source Code     : https://sourceforge.net/projects/espeasy/
   Support         : http://www.esp8266.nu
   Discussion      : http://www.esp8266.nu/forum/

   Additional information about licensing can be found at : http://www.gnu.org/licenses
  \*************************************************************************************************************************/

// This file is to be loaded onto an Arduino Pro Mini so it will act as a simple IO extender to the ESP module.
// Communication between ESP and Arduino is using the I2C bus, so only two wires needed.
// It best to run the Pro Mini on 3V3, although the 16MHz versions do not officially support this voltage level on this frequency.
// That way, you can skip levelconverters on I2C.
// Arduino Mini Pro uses A4 and A5 for I2C bus. ESP I2C can be configured but they are on GPIO-4 and GPIO-5 by default.

#include <Wire.h>

#define I2C_MSG_IN_SIZE    4
#define I2C_MSG_OUT_SIZE   4

#define CMD_DIGITAL_WRITE  1
#define CMD_DIGITAL_READ   2
#define CMD_ANALOG_WRITE   3
#define CMD_ANALOG_READ    4

/*************************************************************************************************************************/

#include <Servo.h>

#define Servo_port 40       //if port is 40 then excute servo task  
Servo myservo;  // create servo object to control a servo

#define dc_motor_pwm 50         //if port is 50 then excute dc motor task (speed)
#define line_follower 100       //if port is 100 then excute dc line follower task
#define buzzer_task 46
#define led_task 45
#define forward_task 51
#define reverse_task 52

#define servo_pin 9           //
#define ena        6           // l298 en pin connected to arduino
#define forward_pin      5           // l298 forward pin connected to arduino
#define reverse_pin      4           // l298 reverse pin connected to arduino
#define led_pin        3       // led pin connected to arduino
#define buzzer_pin       2      // buzzer pin connected to arduino

/*************************************************************************************************************************/
volatile uint8_t sendBuffer[I2C_MSG_OUT_SIZE];

void setup()
{
  myservo.attach(servo_pin);

  Wire.begin(0x7f);
  Wire.onReceive(receiveEvent);
  Wire.onRequest(requestEvent);
}

void loop() {}

void receiveEvent(int count)
{
  if (count == I2C_MSG_IN_SIZE)
  {
    byte cmd = Wire.read();
    byte port = Wire.read();
    int value = Wire.read();
    value += Wire.read() * 256;
    switch (cmd)
    {
      case CMD_DIGITAL_WRITE:

/*************************************************************************************************************************/
      
        if (port == Servo_port) {           // excute servo
            myservo.write(70 + (value * 2));             // sets the servo position according to the scaled value
          delay(5);
        }
        else if (port == dc_motor_pwm) {          // excute
          analogWrite(ena, value * 2);
        }
        else if (port == led_task) {          // excute
          digitalWrite(led_pin, value);
        }
        else if (port == buzzer_task) {          // excute
          digitalWrite(buzzer_pin, value);
        }
         else if (port == forward_task) {          // excute
          digitalWrite(forward_pin, value);
        }
        else if (port == reverse_task) {          // excute
          digitalWrite(reverse_pin, value);
        }
        else if (port == line_follower) {          // excute
          if (value==1){
            //exute line follower
          }
          else {
            //disable line follower 
          }
        }

 
/*************************************************************************************************************************/       
        else
        {
          pinMode(port, OUTPUT);
          digitalWrite(port, value);
        }
        break;
      case CMD_DIGITAL_READ:
        pinMode(port, INPUT_PULLUP);
        clearSendBuffer();
        sendBuffer[0] = digitalRead(port);
        break;
      case CMD_ANALOG_WRITE:
        analogWrite(port, value);
        break;
      case CMD_ANALOG_READ:
        clearSendBuffer();
        int valueRead = analogRead(port);
        sendBuffer[0] = valueRead & 0xff;
        sendBuffer[1] = valueRead >> 8;
        break;
    }
  }
}

void clearSendBuffer()
{
  for (byte x = 0; x < sizeof(sendBuffer); x++)
    sendBuffer[x] = 0;
}

void requestEvent()
{
  Wire.write((const uint8_t*)sendBuffer, sizeof(sendBuffer));
}

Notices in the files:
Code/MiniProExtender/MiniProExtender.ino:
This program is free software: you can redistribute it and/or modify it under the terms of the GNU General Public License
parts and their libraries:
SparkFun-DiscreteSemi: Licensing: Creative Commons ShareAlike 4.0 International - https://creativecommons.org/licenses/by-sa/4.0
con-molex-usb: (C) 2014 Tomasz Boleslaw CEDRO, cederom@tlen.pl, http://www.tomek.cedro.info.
